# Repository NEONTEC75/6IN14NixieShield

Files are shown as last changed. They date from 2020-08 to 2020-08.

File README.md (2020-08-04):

# 6IN14NixieShield
This shield is just a minimal Nixie multiplexed circuit and contains the following components:
- 74141 nixie cathode driver IC (pins 4, 6, 7, 5);
- TLP627 opto-couplers for anodes (pins 12, 11, 9, 8, A1, A2, and pin 10 for the dots);
- 3-button resistive keyboard (A3);
- simple boost converter driven by Arduino's PWM (pin 3, and pin A0 for output voltage feedback);
- DS3231 module connector.

The library with some examples:
https://github.com/NEONTEC75/Nixie6IN14

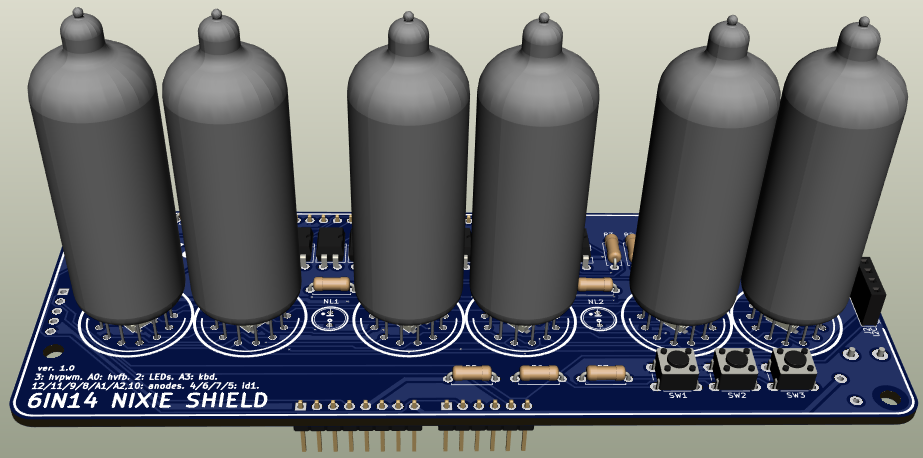
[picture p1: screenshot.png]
6IN14 Nixie Shield


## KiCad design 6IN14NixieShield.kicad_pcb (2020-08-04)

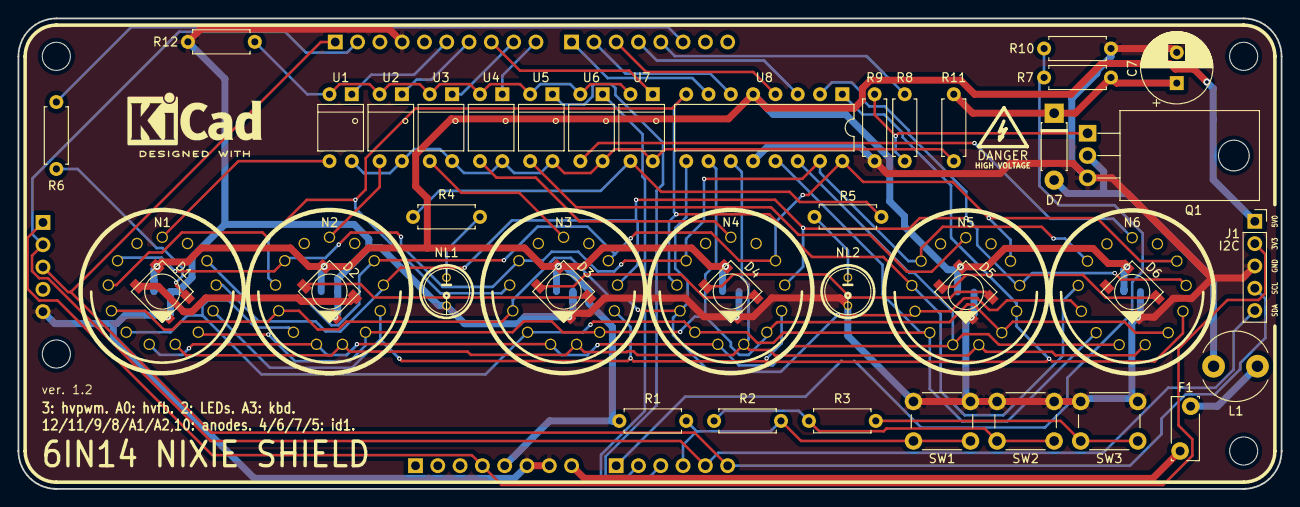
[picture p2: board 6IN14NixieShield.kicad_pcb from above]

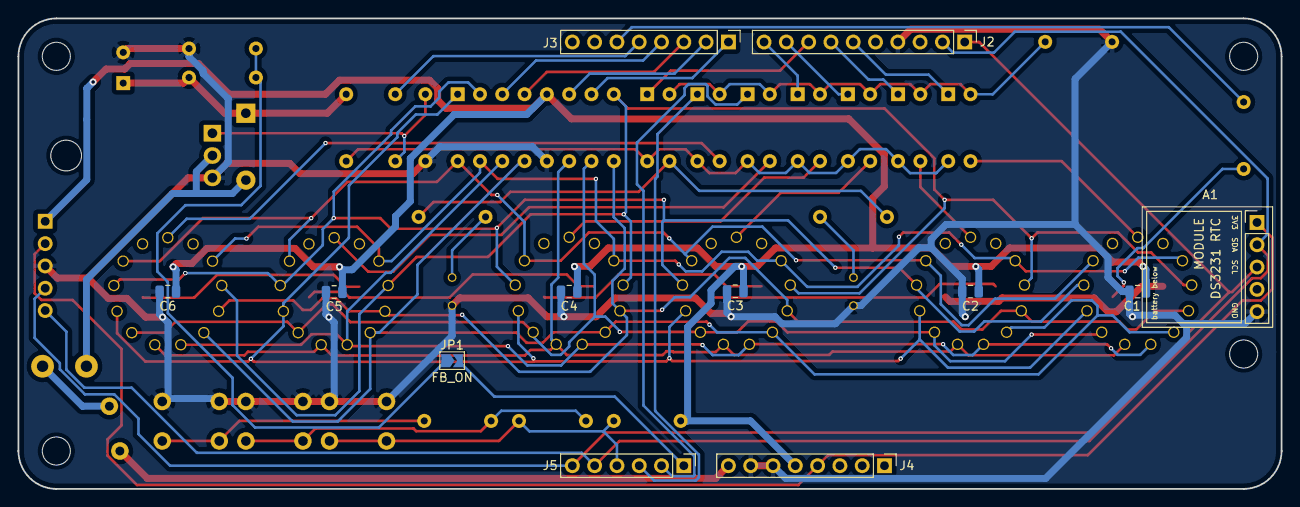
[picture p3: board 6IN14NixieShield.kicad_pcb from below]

Board: 2 copper layers, 143.9 x 53.6 mm, 61 parts (12 on the bottom side), 55 nets.

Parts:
A1: DS3231
C1, C2, C3, C4, C5, C6: 100n; C_0805_2012Metric
C7: 4.7uF*350V; CP_Radial_D8.0mm_P3.50mm
D1, D2, D3, D4, D5, D6: WS2812B
D7: HER106; D_DO-41_SOD81_P7.62mm_Horizontal
F1: 1A; Fuse_Bourns_MF-RG300
H1, H2, H3, H4: MountingHole; MountingHole_3.2mm_M3_DIN965
HVSIGN: Symbol_HighVoltage_Type2_SilkScreen_VerySmall
J1: I2C; PinSocket_1x05_P2.54mm_Vertical
J2: UNO3; PinHeader_1x10_P2.54mm_Vertical
J3: UNO4; PinHeader_1x08_P2.54mm_Vertical
J4: UNO1; PinHeader_1x08_P2.54mm_Vertical
J5: UNO2; PinHeader_1x06_P2.54mm_Vertical
JP1: FB_ON; SolderJumper-2_P1.3mm_Open_TrianglePad1.0x1.5mm
KICADLOGO: KiCad-Logo2_6mm_SilkScreen
L1: 470uH; L_Radial_D7.8mm_P5.00mm_Fastron_07HCP
N1, N2, N3, N4, N5, N6: IN-14; IN-14new
NL1, NL2: NeonLamp
Q1: IRF740; TO-220-3_Horizontal_TabDown
R1, R2, R3: 10k; R_Axial_DIN0207_L6.3mm_D2.5mm_P7.62mm_Horizontal
R4, R5, R10: 4k7; R_Axial_DIN0207_L6.3mm_D2.5mm_P7.62mm_Horizontal
R6: 100; R_Axial_DIN0207_L6.3mm_D2.5mm_P7.62mm_Horizontal
R7: 300k; R_Axial_DIN0207_L6.3mm_D2.5mm_P7.62mm_Horizontal
R8: 22; R_Axial_DIN0207_L6.3mm_D2.5mm_P7.62mm_Horizontal
R9: 100k; R_Axial_DIN0207_L6.3mm_D2.5mm_P7.62mm_Horizontal
R11: 2k2; R_Axial_DIN0207_L6.3mm_D2.5mm_P7.62mm_Horizontal
R12: 470; R_Axial_DIN0207_L6.3mm_D2.5mm_P7.62mm_Horizontal
SW1, SW2, SW3: SW_Push; SW_PUSH_6mm_H4.3mm
U1, U2, U3, U4, U5, U6, U7: TLP627
U8: K155ID1; DIP-16_W7.62mm

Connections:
+3V3: A1.1, J1.2, J4.4
+5V: C1.1, C2.1, C3.1, C4.1, C5.1, C6.1, D1.1, D2.1, D3.1, D4.1, D5.1, D6.1, J1.1, J4.5, R1.1, U8.5
/A0: J5.1, JP1.2
/A1: J5.2, U5.1
/A2: J5.3, U6.1
/A3: J5.4, R1.2, R2.1, SW1.1
/A4: A1.2, J1.5, J2.2, J5.5
/A5: A1.3, J1.4, J2.1, J5.6
/BOOST_PWM: J3.5, R8.2
/CTL_A1: J2.6, U1.1
/CTL_A2: J2.7, U2.1
/CTL_A3: J2.9, U3.1
/CTL_A4: J2.10, U4.1
/CTL_Adots: J2.8, U7.1
/D2: J3.6, R6.1
/D4: J3.4, U8.3
/D5: J3.3, U8.4
/D6: J3.2, U8.6
/D7: J3.1, U8.7
/NixieCtl/+HV: C7.1, D7.1, R7.2, R11.1
/NixieCtl/ANODE_1: N1.A, U1.3
/NixieCtl/ANODE_2: N2.A, U2.3
/NixieCtl/ANODE_3: N3.A, U3.3
/NixieCtl/ANODE_4: N4.A, U4.3
/NixieCtl/ANODE_5: N5.A, U5.3
/NixieCtl/ANODE_6: N6.A, U6.3
/NixieCtl/CATHODE_0: N1.0, N2.0, N3.0, N4.0, N5.0, N6.0, U8.16
/NixieCtl/CATHODE_1: N1.1, N2.1, N3.1, N4.1, N5.1, N6.1, U8.15
/NixieCtl/CATHODE_2: N1.2, N2.2, N3.2, N4.2, N5.2, N6.2, U8.8
/NixieCtl/CATHODE_3: N1.3, N2.3, N3.3, N4.3, N5.3, N6.3, U8.9
/NixieCtl/CATHODE_4: N1.4, N2.4, N3.4, N4.4, N5.4, N6.4, U8.13
/NixieCtl/CATHODE_5: N1.5, N2.5, N3.5, N4.5, N5.5, N6.5, U8.14
/NixieCtl/CATHODE_6: N1.6, N2.6, N3.6, N4.6, N5.6, N6.6, U8.11
/NixieCtl/CATHODE_7: N1.7, N2.7, N3.7, N4.7, N5.7, N6.7, U8.10
/NixieCtl/CATHODE_8: N1.8, N2.8, N3.8, N4.8, N5.8, N6.8, U8.1
/NixieCtl/CATHODE_9: N1.9, N2.9, N3.9, N4.9, N5.9, N6.9, U8.2
/Tubes/ANODE_DOTS: R4.2, R5.2, U7.3
/VIN: F1.1, J4.8
GND: A1.5, C1.2, C2.2, C3.2, C4.2, C5.2, C6.2, C7.2, D1.3, D2.3, D3.3, D4.3, D5.3, D6.3, J1.3, J2.4, J4.6, J4.7, NL1.2, NL2.2, Q1.3, R9.2, R10.1, R12.2, SW1.2, SW2.2, SW3.2, U8.12
unnamed: D1.2, D2.4
unnamed: D1.4, R6.2
unnamed: D2.2, D3.4
unnamed: D3.2, D4.4
unnamed: D4.2, D5.4
unnamed: D5.2, D6.4
unnamed: D7.2, L1.1, Q1.2
unnamed: F1.2, L1.2
unnamed: JP1.1, R7.1, R10.2
unnamed: NL1.1, R4.1
unnamed: NL2.1, R5.1
unnamed: Q1.1, R8.1, R9.1
unnamed: R2.2, R3.1, SW2.1
unnamed: R3.2, SW3.1
unnamed: R11.2, U1.4, U2.4, U3.4, U4.4, U5.4, U6.4, U7.4
unnamed: R12.1, U1.2, U2.2, U3.2, U4.2, U5.2, U6.2, U7.2
